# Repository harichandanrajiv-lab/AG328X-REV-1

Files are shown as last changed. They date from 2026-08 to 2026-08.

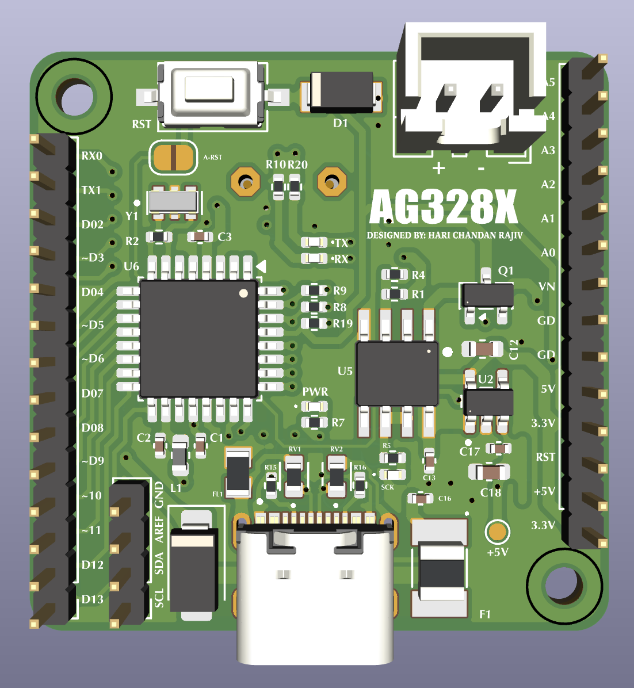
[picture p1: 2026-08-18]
Board Images/Top View.png

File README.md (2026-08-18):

# AG328X-REV-1
AG328X REV-1 is a compact, redesigned implementation of the Arduino UNO platform, developed with
the objective of improving the original UNO architecture in terms of form factor, power architecture, USB
connectivity, protection, serviceability, and PCB integration.

The design retains the core functionality based on the ATmega328P, while keeping a dedicated
ATmega16U2 USB-to-serial interface and a redesigned power-management architecture. Rather than
directly reproducing the conventional reference design, AG328X restructures several functional sections to
achieve a more compact and integrated hardware platform.

The complete PCB is designed with an overall dimension of 34 mm × 34 mm, a 1.6 mm finished board
thickness, and a 4-layer PCB stack-up, which is 68.44% smaller in size compared to the original UNO board.
The four-layer implementation provides additional routing resources and dedicated copper areas for power
and ground distribution, enabling the compact board dimensions without compromising the electrical
organization of the design. For further info, go through @Documentation Section.

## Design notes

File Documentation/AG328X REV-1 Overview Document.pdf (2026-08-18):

# AG328X REV-1 Description

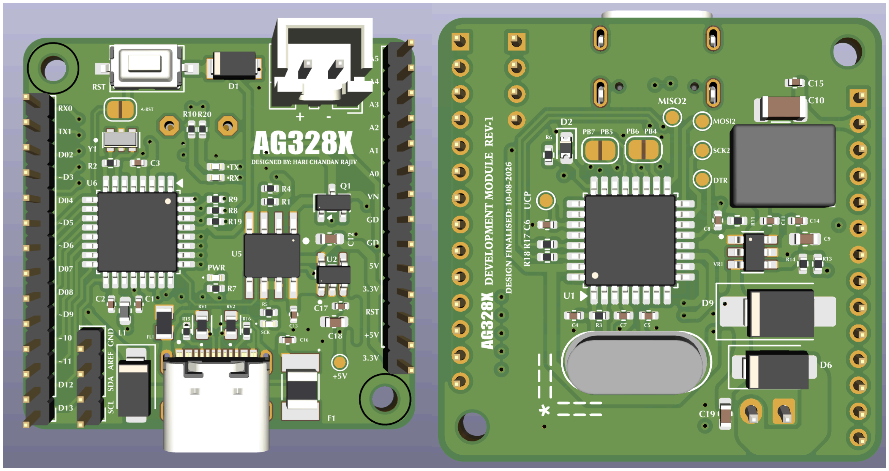
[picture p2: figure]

## 1.1 Introduction

AG328X REV-1 is a compact, redesigned implementation of the Arduino UNO platform, developed with the objective of improving the original UNO architecture in terms of form factor, power architecture, USB connectivity, protection, serviceability, and PCB integration.

The design retains the core functionality based on the ATmega328P, while keeping a dedicated
ATmega16U2 USB-to-serial interface and a redesigned power-management architecture. Rather than directly reproducing the conventional reference design, AG328X restructures several functional sections to achieve a more compact and integrated hardware platform.

The complete PCB is designed with an overall dimension of 34 mm × 34 mm, a 1.6 mm finished board thickness, and a 4-layer PCB stack-up, which is 68.44% smaller in size compared to the original UNO board. The four-layer implementation provides additional routing resources and dedicated copper areas for power and ground distribution, enabling the compact board dimensions without compromising the electrical organization of the design.

AG328X REV-1 ⬩ Designed by Hari Chandan Rajiv ⬩ 1

## 1.2 Design Objective

The primary objective of AG328X REV-1 is to develop a smaller and more technically refined UNO-compatible hardware platform while maintaining the essential functionality. The redesign focuses on the following engineering objectives:

- Reduction of the overall PCB footprint.
- Integration of the complete ATmega328P-based controller architecture onto a compact board.
- Replacement of the conventional USB-B connector arrangement with USB Type-C.
- Improvement of the input power and regulation architecture.
- Improvement on maximum input voltage VIN capability.
- Replacement of DC jack with a 2 pin JST connector for easy power connection.
- Controlled generation of the 3.3 V rail, including VIN/USBVCC source selection.
- Incorporation of input protection and power filtering.
- Improved PCB routing capability through a 4-layer architecture.
- Maintaining access to the standard Arduino I/O functionality through board connectors.

## 1.3 System Architecture

The AG328X REV-1 hardware is organized around two primary microcontrollers:

1. ATmega328P — Main application microcontroller responsible for the Arduino-compatible processing and I/O functionality.
2. ATmega16U2 — Dedicated USB interface controller responsible for USB-to-UART communication with the ATmega328P.

The schematic is divided into functional blocks covering the USB interface, power management, microcontroller circuitry, indication circuitry, and external I/O interfaces. The power architecture is independently organized around the incoming VIN and USB VCC sources. The design includes a dedicated 5 V regulator section for generating the primary regulated supply and a separate 3.3 V supply section with source-selection circuitry. Input protection, filtering, bulk capacitance, and local decoupling are incorporated around the power stages to improve supply integrity.

The USB section uses a USB Type-C connector together with the required CC configuration and USB signal routing. A ferrite-bead-based filtering arrangement is also incorporated into the USB-related power/ground path.

AG328X REV-1 ⬩ Designed by Hari Chandan Rajiv ⬩ 2

# 2. Technical Specifications

## 2.1 Electrical and System Specifications

Parameter | AG328X REV-1 Specification | Design Basis
Main Controller | ATmega328P-AU | 32 KB Flash, 2 KB SRAM, 1 KB EEPROM
USB Controller | ATmega16U2 | Dedicated USB-to-UART interface
Main Logic Voltage | 5 V | Regulated supply
Auxiliary Logic Voltage | 3.3 V | Dedicated LDO
VIN Input | 17 V maximum | Regulator Input capability
5 V Regulator Input Capability | 4.5–17 V | TPS561208-class buck regulator
3.3 V LDO Input | 5.5 V maximum | TLV70233
USB Interface | USB 2.0 | ATmega16U2

AG328X REV-1 ⬩ Designed by Hari Chandan Rajiv ⬩ 3

USB Connector | USB Type-C | For easy power and coding accessibility
PCB Dimensions | 34 mm × 34 mm | Mechanical design
Reverse Polarity Protection | FDN340P | PMOS transistor based reverse polarity and dual input protection
PCB Thickness | 1.6 mm | PCB specification
PCB Layer Count | 4 layers | Routing and ground/power architecture

The ATmega328P supports a 1.8–5.5 V supply range, while the ATmega16U2 supports 2.7–5.5 V. Both therefore operate within their specified supply ranges on the 5 V AG328X logic rail. (Microchip) (https://www.microchip.com/en-us/product/ATmega328p?utm_source=chatgpt.com)

## 2.2 VIN Capability and Input Protection

The VIN power path is one of the major improvements in AG328X REV-1. The input passes through a resettable PPTC fuse, reverse-polarity protection diode, and transient-voltage suppression device before reaching the regulator stage.

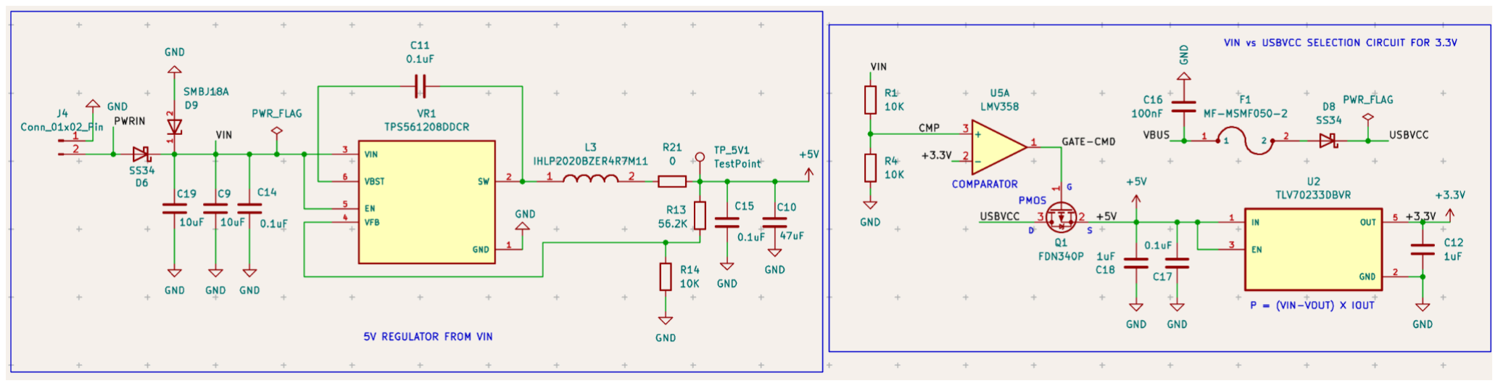
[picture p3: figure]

### VIN Rating Analysis

AG328X REV-1 ⬩ Designed by Hari Chandan Rajiv ⬩ 4

The selected 5 V switching regulator provides an input operating range extending to 17 V. For the TPS561201, for example, the specified input range is 4.5–17 V, with a 1 A output capability. (Texas Instruments) (https://www.ti.com/product/TPS561201?utm_source=chatgpt.com)

However, the overall AG328X VIN rating is determined by the lowest-rated component in the VIN path, not by the regulator alone.

The selected Bourns MF-MSMF050-2 has:

- Hold current: 500 mA
- Trip current: 1 A
- Maximum voltage: 15 VDC
- Maximum current: 100 A
- Maximum resistance: approximately 1 Ω (Mouser Electronics) (https://www.mouser.com/en/ProductDetail/Bourns/MF-MSMF050-2?qs=t3shhpq1i1DZ7OBD5kLNoA%3D%3D)

Therefore: The present AG328X REV-1 VIN capability should be 15 V maximum, not 17 V.

The 17 V capability of the buck regulator provides voltage headroom within the regulator itself, but the 15 V PPTC rating limits the complete input path.

### Input Protection Devices

The VIN protection network includes the following devices:

Component | Selected Part | Rating / Function
F1 | MF-MSMF050-2 | 500 mA hold, 1 A trip, 15 V maximum
D6 | SS34 | Schottky reverse-polarity protection
D9 | SMBJ18A | 18 V TVS protection
C19/C9/C14 | Input capacitors | VIN filtering and transient energy storage

AG328X REV-1 ⬩ Designed by Hari Chandan Rajiv ⬩ 5

The SMBJ18A provides an 18 V working standoff voltage, 20 V minimum breakdown voltage and approximately 29.2 V maximum clamping voltage, with a 600 W peak pulse capability for the specified pulse condition. (Diodes Incorporated) (https://www.diodes.com/part/view/SMBJ18A?utm_source=chatgpt.com)

This provides appropriate transient protection around the intended VIN region, but it does not change the continuous operating-voltage limit imposed by the PPTC fuse.

## 2.3 5 V Power Supply

AG328X REV-1 uses a dedicated synchronous buck regulator to generate the primary 5 V rail from VIN.

The selected regulator is a TPS56x-series 17 V-input synchronous step-down converter. The relevant device family provides:

- Input voltage: 4.5–17 V
- Output voltage range: approximately 0.76–7 V
- Synchronous rectification
- Integrated switching MOSFETs
- Cycle-by-cycle overcurrent protection
- Hiccup-mode overcurrent protection
- Thermal shutdown
- Undervoltage protection
- Approximately 580 kHz switching frequency for the TPS56120x family. (Texas Instruments) (https://www.ti.com/product/TPS561201?utm_source=chatgpt.com)

The regulator is configured for a fixed 5 V output, which becomes the primary supply rail for the ATmega328P, ATmega16U2 and associated 5 V circuitry.

### System Implication

The regulator selection provides considerably more input-voltage capability than the conventional 5 V logic rail requires:

VIN → Protection → 5 V Buck Converter → +5 V Logic Rail

The important distinction is:

- Regulator capability: up to 17 V
- Present AG328X system VIN rating: 15 V
- Reason: MF-MSMF050-2 maximum voltage rating

AG328X REV-1 ⬩ Designed by Hari Chandan Rajiv ⬩ 6

This distinction is maintained throughout this document to prevent confusing individual component ratings with the system rating.

## 2.4 3.3 V Power Supply

The 3.3 V rail is generated using the TLV70233 low-dropout regulator.

The TLV70233 is a fixed 3.3 V LDO with:

- Output voltage: 3.3 V
- Output current capability: 300 mA
- Maximum input voltage: 5.5 V
- Low quiescent current
- Low-noise operation
- Thermal and current protection. (Texas Instruments) (https://www.ti.com/lit/ds/symlink/tlv700-q1.pdf?ts=1778681428301&utm_source=chatgpt.com)

In AG328X, the regulator is supplied from the 5 V domain, rather than directly from VIN.

Therefore, the 3.3 V regulator does not impose a 5.5 V limit on the AG328X VIN input.

The power architecture can consequently be represented as:

VIN → 5 V Buck → 5 V Rail → 3.3 V LDO → 3.3 V Rail

This allows the board to accept the higher VIN voltage permitted by the upstream power architecture while keeping the 3.3 V regulator safely within its input specification.

## 2.5 3.3 V Supply-Source Selection

AG328X REV-1 incorporates an active supply-selection circuit around an LMV358 comparator and FDN340P P-channel MOSFET to control the 3.3 V supply source.

The LMV358 operates from 2.7–5.5 V and provides rail-to-rail output capability, making it suitable for the 5 V-powered comparison/control section used in the design. (Texas Instruments) (https://www.ti.com/product/LMV358?utm_source=chatgpt.com)

The selected FDN340P is a logic-level P-channel MOSFET with:

AG328X REV-1 ⬩ Designed by Hari Chandan Rajiv ⬩ 7

- Drain-source voltage: 20 V
- Continuous drain current: approximately 2 A
- RDS(on): approximately 70 mΩ at VGS = −4.5 V
- Maximum gate-source voltage: ±8 V
- Power dissipation: approximately 500 mW
- SOT-23 package. (DigiKey) (https://www.digikey.com/en/htmldatasheets/production/64543/0/0/1/fdn340p.html?utm_source=chatgpt.com)

This provides adequate voltage margin for the 5 V-domain source-selection function.

## 2.6 5 V Regulator Architecture and Power-Loss Improvement

A significant change in AG328X REV-1 is the replacement of the conventional 5 V linear/LDO regulation approach with a switching buck regulator.

This change was made primarily to reduce power dissipation and improve power-conversion efficiency, particularly when AG328X is operated from a higher VIN voltage.

### Linear Regulator vs. Switching Regulator

With a conventional linear regulator, the excess input voltage is dissipated directly as heat. The regulator power loss is approximately:

PLOSS(LDO) = (VIN − VOUT) × IOUT

For the AG328X 5 V rail:

PLOSS(LDO) = (VIN − 5 V) × IOUT

As VIN increases, the voltage dropped across the regulator increases, causing a corresponding increase in heat generation.

In contrast, the switching buck regulator used in AG328X transfers energy from the input to the output through high-frequency switching. Its power loss is primarily determined by the converter’s efficiency:

PLOSS(BUCK) = POUT × (1/η − 1)

where:

- POUT = output power
- η = converter efficiency

AG328X REV-1 ⬩ Designed by Hari Chandan Rajiv ⬩ 8

Therefore, the switching architecture avoids dissipating the entire VIN-to-5 V voltage difference as heat.

### Example Power-Loss Comparison

Consider a representative operating condition of:

- VIN = 15 V
- VOUT = 5 V
- IOUT = 500 mA

The 5 V output power is:

POUT = 5 V × 0.5 A = 2.5 W

a. Conventional LDO

For a linear regulator: PLOSS = (15 − 5) × 0.5 = 5 W

The regulator would therefore need to dissipate approximately 5 W as heat while delivering only 2.5 W to the 5 V load. The theoretical efficiency would be:

ηLDO = 5/15 ≈ 33.3%

This creates a significant thermal-management requirement and makes operation from higher VIN voltages inefficient.

b. Switching Buck Regulator

Assuming a representative converter efficiency of 90%:

PIN = 2.5 W / 0.90 ≈ 2.78 W

Therefore: PLOSS ≈ 2.78 − 2.5 = 0.28 W

Parameter | 5 V LDO | 5 V Switching Regulator

AG328X REV-1 ⬩ Designed by Hari Chandan Rajiv ⬩ 9

VIN | 15 V | 15 V
VOUT | 5 V | 5 V
Load Current | 500 mA | 500 mA
Output Power | 2.5 W | 2.5 W
Approx. Efficiency | 33.3% | ~90%*
Approx. Regulator Loss | 5.0 W | 0.28 W*
Heat Generation | High | Significantly lower

Actual switching-regulator efficiency depends on VIN, load current, switching frequency, inductor, PCB layout, temperature, and other operating conditions. The 90% value is an illustrative engineering example and should not be treated as the guaranteed AG328X efficiency.

### Effect on AG328X

The change to a switching 5 V regulator provides several practical advantages:

### 1. Lower power dissipation

The voltage difference between VIN and 5 V is no longer converted predominantly into heat.

### 2. Improved efficiency at higher VIN

The advantage becomes increasingly significant as VIN increases.

### 3. Reduced thermal stress

Lower regulator dissipation reduces junction-temperature rise and thermal stress on the PCB.

AG328X REV-1 ⬩ Designed by Hari Chandan Rajiv ⬩ 10

### 4. Improved usable VIN range

The selected switching regulator supports input voltages up to 17 V, while the present AG328X system-level VIN rating is limited to 15 V by the MF-MSMF050-2 input protection fuse.

### 5. Better suitability for continuous operation

Lower dissipation is particularly advantageous when the board operates continuously or is enclosed with limited airflow.

### 6. Higher practical power capability

Because less input power is lost as heat, a larger portion of the available input power can be delivered to the 5 V rail.

### Engineering Significance

The regulator change is therefore not simply a component substitution. It represents a power-architecture improvement in AG328X REV-1.

Design conclusion: The adoption of a switching regulator for the 5 V rail significantly reduces the power that would otherwise be dissipated as heat by a linear regulator, making the AG328X power architecture more efficient and thermally suitable for operation from higher VIN voltages.

## 2.7 Current Consumption and Power-Architecture Comparison

A further objective of AG328X REV-1 is to reduce unnecessary power consumption and, more importantly, reduce the power lost within the board’s voltage-regulation circuitry.

### Arduino UNO R3 Reference

The Arduino UNO R3 is specified for a 5 V operating voltage and uses a linear regulation approach when powered through VIN. Arduino’s current power-supply guidance indicates that a basic Arduino board typically requires approximately 50 mA, excluding external loads connected to the board. (Arduino Help Center) (https://support.arduino.cc/hc/en-us/articles/360018922259-What-power-supply-can-I-use-with-my-Arduino-board)

The actual input power when using VIN depends strongly on the applied voltage because a linear regulator dissipates the voltage difference as heat.

For example, at:

- VIN = 12 V
- 5 V rail current = 50 mA

AG328X REV-1 ⬩ Designed by Hari Chandan Rajiv ⬩ 11 the approximate regulator dissipation is: PLOSS = (12 − 5) × 0.05 = 0.35 W

The input power associated with the 50 mA load is approximately: PIN = 12 × 0.05 = 0.60 W

while the useful 5 V power is: POUT = 5 × 0.05 = 0.25 W

This illustrates why the UNO’s linear-regulator architecture becomes increasingly inefficient as VIN increases.

### AG328X REV-1

AG328X replaces the conventional 5 V linear-regulation approach with a switching buck regulator. Consequently, the input current is no longer approximately equal to the 5 V load current when operating from VIN.

For a buck converter:

IIN ≈ (VOUT × IOUT) / (VIN × η)

where η is the converter efficiency.

For example, assuming:

- VIN = 12 V
- 5 V load current = 50 mA
- Converter efficiency = 90%

the approximate VIN current becomes:

IIN ≈ (5 × 0.05) / (12 × 0.90) ≈ 23 mA

The corresponding input power is approximately:

PIN ≈ 12 × 23 mA ≈ 0.28 W

Therefore, compared with a linear regulator, the switching architecture substantially reduces the power drawn from VIN for the same 5 V load and dramatically reduces regulator heat dissipation.

### Preliminary Comparison

AG328X REV-1 ⬩ Designed by Hari Chandan Rajiv ⬩ 12

Parameter | Arduino UNO R3 | AG328X REV-1

The AG328X value is an engineering calculation based on an assumed 50 mA 5 V load and 90% converter efficiency. It is not a measured AG328X specification.

AG328X REV-1 ⬩ Designed by Hari Chandan Rajiv ⬩ 13

Main MCU | ATmega328P | ATmega328P
USB MCU | ATmega16U2 | ATmega16U2
Logic Voltage | 5 V | 5 V
5 V Regulation | Linear | Switching Buck
Typical board current* | ~50 mA | To be measured
VIN example | 12 V | 12 V
5 V load used for example | 50 mA | 50 mA
Approx. VIN current at 12 V | ~50 mA | ~23 mA*
Approx. regulator loss | ~350 mW | ~28 mW*
Regulation efficiency | ~42% theoretical | ~90% assumed*

### Engineering Conclusion

The principal improvement is therefore not necessarily that AG328X consumes fewer milliamps at every operating condition. The more significant improvement is that AG328X requires less input power and generates substantially less heat when converting higher VIN voltages to the 5 V logic rail.

For the same 5 V load:

Arduino UNO linear regulation:

Higher VIN → approximately same input current → higher power loss

AG328X switching regulation:

Higher VIN → lower input current → substantially lower power loss

This makes the AG328X architecture more suitable for compact applications where thermal dissipation, continuous operation, and power efficiency are important design considerations.

AG328X REV-1 ⬩ Designed by Hari Chandan Rajiv ⬩ 14

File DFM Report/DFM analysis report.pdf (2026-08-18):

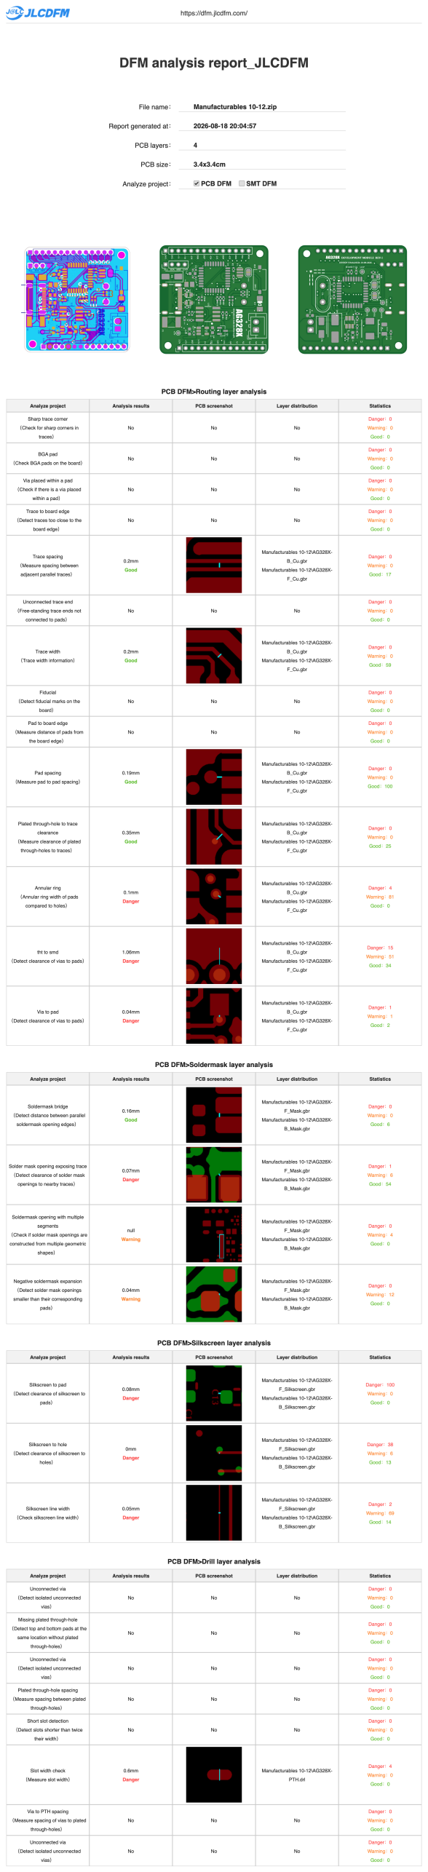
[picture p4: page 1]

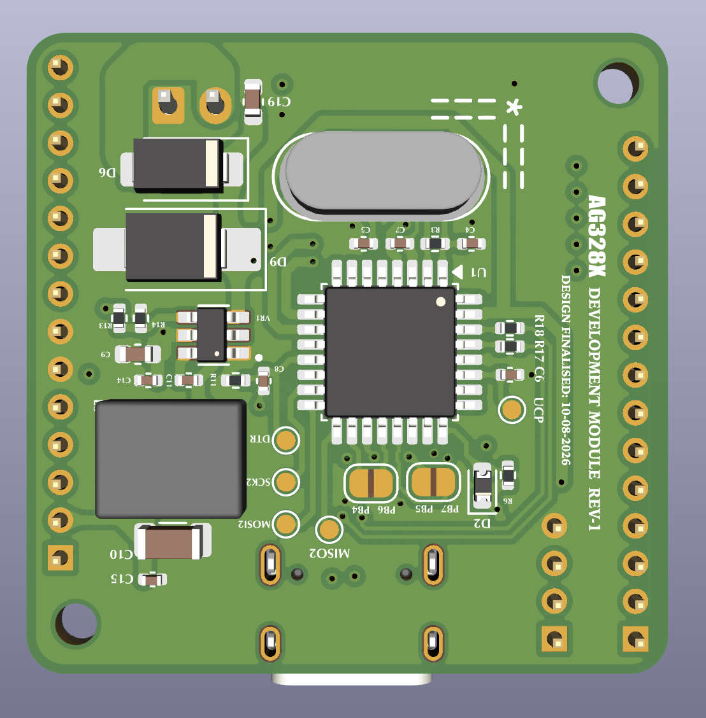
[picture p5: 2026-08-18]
Board Images/Bottom View.png

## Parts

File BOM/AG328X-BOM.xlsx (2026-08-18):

AG328X
Id | Designator | Footprint | Designation | Quantity | Cost | Total | Source Link
1 | C1, C2, C3, C7, C8, C13, C16 | C_0402_1005Metric | 100nF | 7 | 0.5 | 3.5 | https://robu.in/product/gcm155r71h104ke02j-murata-electronics-50v-100nf-x7r-%C2%B110-0402-multilayer-ceramic-capacitors-mlcc-smd-smt-rohs/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
2 | C4, C5 | C_0402_1005Metric | 22pF | 2 | 0.23 | 0.46 | https://robu.in/product/grm1555c1h220ga01d-murata-cap-ceramic-22pf-50v-c0g-2-pad-smd-0402-125c-t-r/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
3 | C6 | C_0402_1005Metric | 1uF | 1 | 0.31 | 0.31 | https://robu.in/product/grm155b31c105ka12d-murata-cap-ceramic-1uf-16v-b-10-pad-smd-0402-85c-t-r/?gad_source=1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
4 | C9, C19 | C_0603_1608Metric | 10uF | 2 | 2.34 | 4.68 | https://robu.in/product/grm188r61e106ma73d-murata-cap-ceramic-10uf-25v-x5r-20-pad-smd-0603-85c-automotive-t-r/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
5 | C10 | C_1206_3216Metric | 47uF | 1 | 33 | 33 | https://robu.in/product/grm31cr61e476me44l-murata-25v-47uf-x5r-%25c2%25b120-1206-multilayer-ceramic-capacitors-mlcc-smd-smt-rohs/
6 | C11, C14, C15, C17 | C_0402_1005Metric | 0.1uF | 4 | 0.5 | 2 | https://robu.in/product/gcm155r71h104ke02j-murata-electronics-50v-100nf-x7r-%C2%B110-0402-multilayer-ceramic-capacitors-mlcc-smd-smt-rohs/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
7 | C12, C18 | C_0603_1608Metric | 1uF | 2 | 0.5 | 1 | https://robu.in/product/grm188r71e105ka12d-murata-cap-ceramic-1uf-25v-x7r-10-pad-smd-0603-125c-t-r/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
8 | D1 | SS14 | DO-214AC | 1 | 1.35 | 1.35 | https://robu.in/product/ss14-slkor-40v-550mv1a-1a-smado-214ac-schottky-diodes-rohs/?gad_source=1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
9 | D2 | D_0603_1608Metric | SDM2U30CSP-7B | 1 | 16 | 16 | https://robu.in/product/sdm2u30csp-7b-diodes-incorporated-30v-480mv2a-2a-0603-schottky-diodes-rohs/
10 | D3 | LED_0402_1005Metric | LED - WHITE | 1 | 1.69 | 1.69 | https://robu.in/product/0402-surface-mount-led-white/
11 | D4 | LED_0402_1005Metric | LED-ORANGE | 1 | 1.79 | 1.79 | https://robu.in/product/0402-surface-mount-led-orange/
12 | D5 | LED_0402_1005Metric | LED - GREEN | 1 | 1.91 | 1.91 | https://robu.in/product/0402-surface-mount-led-green-50-pcs/
13 | D6, D8 | D_SMA | SS34 | 2 | 2.47 | 4.94 | https://robu.in/product/ss34-slkor-40v-500mv3a-3a-smado-214ac-schottky-diodes-rohs/?gad_source=1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
14 | D7 | LED_0402_1005Metric | LED-YELLOW | 1 | 1.77 | 1.77 | https://robu.in/product/0402-surface-mount-led-yellow/
15 | D9 | D_SMB_Handsoldering | SMBJ18A | 1 | 20 | 20 | https://robu.in/product/smbj18a-13-f-diodes-incorporated-20-5a-600w-29-2v-23-3v-unidirectional-18v-smbdo-214aa-esd-and-surge-protection-tvs-esd-rohs/
16 | F1 | FUSM4632X85 | MF-MSMF050-2 | 1 | 40.77 | 40.77 | https://www.lioncircuits.com/parts/MF-MSMF050-2
17 | FL1 | BEADC2012X105N | BLM21PG121SN1D | 1 | 15.93 | 15.93 | https://www.lioncircuits.com/parts/BLM21PG121SN1D
18 | J1 | PinHeader_1x04_P2.00mm_Vertical | Conn_01x04_Socket | 1 | 0 | 0 | https://robu.in/product/2mm-pitch-male-berg-strip-40x1-2pcs/
19 | J2 | GCT_USB4105GFA | USB4105GFA | 1 | 5.5 | 5.5 | https://www.ktron.in/product/16-pin-usb-type-c-connector-smd/
20 | J4 | JST_XA_B02B-XASK-1-A_1x02_P2.50mm_Vertical | Conn_01x02_Pin | 1 | 8 | 8 | https://robu.in/product/2-pin-jst-xh-2-54mm-pitch-plug-and-socket-with-cable-10-pcs/
21 | J11, J12 | PinHeader_1x14_P2.00mm_Vertical | Conn_01x14_Socket | 2 | 12.5 | 25 | https://robu.in/product/2mm-pitch-male-berg-strip-40x1-2pcs/
22 | L1 | L_0603_1608Metric | 10uH | 1 | 3.73 | 3.73 | https://robu.in/product/mlz1608m100wt000-tdk-10-%C2%B5h-shielded-multilayer-inductor-250-ma-1-05ohm-0603-1608-metric/
23 | L3 | INDPM5552X200N | IHLP2020BZER4R7M11 | 1 | 12 | 12 | https://robu.in/product/ihlp2020bzer4r7m11-vishay-power-inductor-smd-4-7-%25c2%25b5h-3-2-a-shielded-3-a/
24 | Q1 | SOT-23 | FDN340P | 1 | 6 | 6 | https://robu.in/product/fdn340p-slkor-20v-3a-1w-70m%CF%894-5v2a-1v-1-piece-p-channel-sot-23-mosfets-rohs/
25 | R1, R4, R6, R14, R19 | R_0402_1005Metric | 10K | 5 | 0.36 | 1.8 | https://robu.in/product/rc0402fr-1010kl-yageo-0-063w-thick-film-resistors-%25c2%25b1100ppm-%25e2%2584%2583-%25c2%25b11-10k%25cf%2589-0402-chip-resistor-surfac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
26 | R2, R3 | R_0402_1005Metric | 1M ohm | 2 | 0.67 | 1.34 | https://robu.in/product/rc0402fr-071ml-yageo-res-thick-film-0402-1m-ohm-1-0-063w1-16w-%C2%B1100ppm-c-pad-smd-t-r/
27 | R5, R8, R9, R10, R11, R20 | R_0402_1005Metric | 1K | 6 | 0.68 | 4.08 | https://robu.in/product/ac0402jr-071kl-yageo-res-thick-film-0402-1k-ohm-5-0-063w1-16w-%C2%B1100ppm-c-pad-smd-t-r-automotive-aec-q200/
28 | R7 | R_0402_1005Metric | 500 | 1 | 0 | 0 | Use 1k
29 | R13 | R_0402_1005Metric | 56.2K | 1 | 0.12 | 0.12 | https://robu.in/product/ac0402fr-0756k2l-yageo-res-thick-film-0402-56-2k-ohm-1-0-063w1-16w-%C2%B1100ppm-c-pad-smd-t-r-automotive-aec-q200/
30 | R15, R16 | R_0402_1005Metric | 5.1K | 2 | 0.13 | 0.26 | https://robu.in/product/rc0402fr-075k1l-yageo-smd-chip-resistor/
31 | R17, R18 | R_0402_1005Metric | 22 ohm | 2 | 0.69 | 1.38 | https://robu.in/product/rc0402fr-0722rl-yageo-smd-chip-resistor-22-ohm-%25c2%25b1-1-100-mw-0402-1005-metric-thick-film-precision-pack-of-10/
32 | RV1, RV2 | VARC1608X56N | CG0603MLC-05E | 2 | 27 | 54 | https://robu.in/product/cg0603mlc-05e-bourns-tvs-varistor-8-v-5-v-chipguard-mlc-20-v-0603-1608-metric-multilayer-varistor-mlv/
33 | SW1 | SW_Tactile_SPST_NO_Straight_CK_PTS636Sx25SMTRLFS | SW_Push | 1 | 2.71 | 2.71 | https://robu.in/product/lck-ta007h27-2wl-lckelec-362-7-patch-260g-tact-switch/
35 | U1 | TQFP-32_7x7mm_P0.8mm | ATmega16U2-A | 1 | 364.679 | 364.679 | https://in.element14.com/microchip/atmega16u2-au/mcu-8bit-16mhz-tqfp-32/dp/1841607
36 | U2 | SOT95P280X145-5N | TLV70233DBVR | 1 | 15.05 | 15.05 | https://www.ktron.in/product/tlv70233dbvr-regulator-ic/
37 | U5 | SO08 | LMV358 | 1 | 11 | 11 | https://robu.in/product/lmv358-slkor-dual-0-3v-us-1mhz-9mv-sop-8-operational-amplifier-rohs/
38 | U6 | TQFP-32_7x7mm_P0.8mm | ATmega328P-A | 1 | 326 | 326 | https://robu.in/product/atmega328p-au-microchip-8-bit-mcu-avr-atmega/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
39 | VR1 | SOT95P280X110-6N | TPS561208DDCR | 1 | 54 | 54 | https://robu.in/product/tps561208ddcr-texas-instruments-step-down-type-adjustable-760mv7v-1a-4-5v17v-tsot-23-6-dc-dc-converters-rohs/
40 | Y1 | OSC_CSTCE16M0V53-R0 | 16MHz Crystal | 1 | 37.52 | 37.52 | https://www.lioncircuits.com/parts/CSTNE16M0VH3C000R0
41 | Y2 | 16MHz Y2 | 16MHz Crystal | 1 | 8 | 8 | https://robu.in/product/hc49-s-16mhz-crystal-oscillator-pack-of-5/
 |  |  |  |  |  | 1093.269

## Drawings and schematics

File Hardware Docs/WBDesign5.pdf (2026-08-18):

## WEBENCH ® Design Report

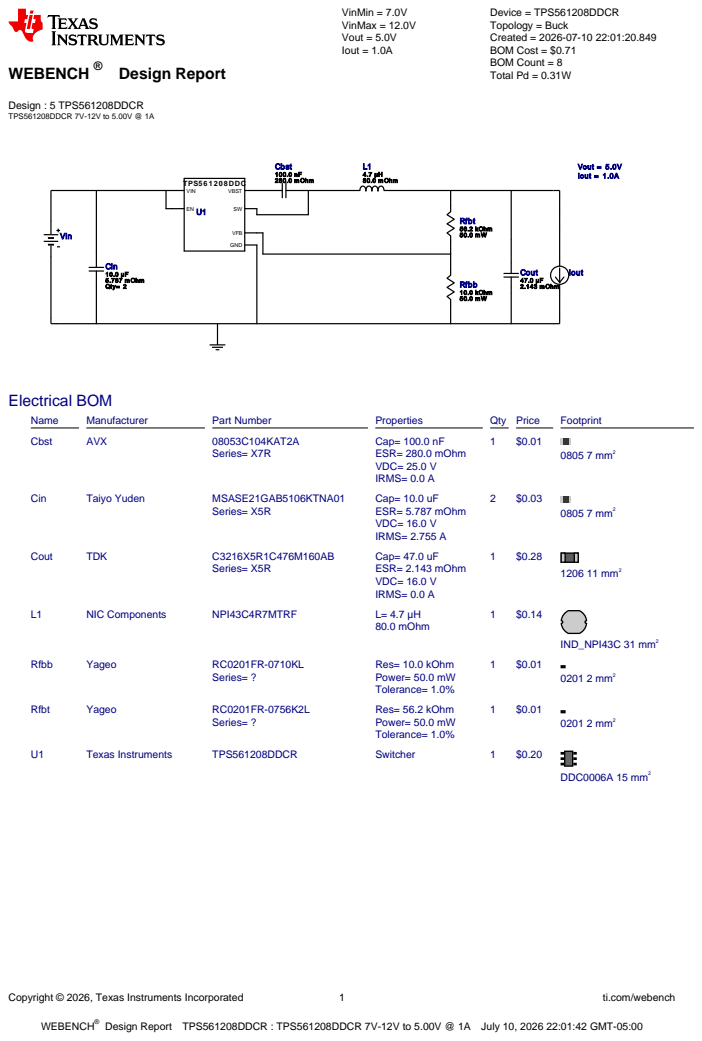
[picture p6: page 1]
Copyright © 2026, Texas Instruments Incorporated; ti.com/webench; WEBENCH®; Design : 5 TPS561208DDCR TPS561208DDCR 7V-12V to 5.00V @ 1A; VinMin = 7.0V VinMax = 12.0V Vout = 5.0V Iout = 1.0A; Device = TPS561208DDCR Topology = Buck Created = 2026-07-10 22:01:20.849 BOM Cost = $0.71 BOM Count = 8 Total Pd = 0.31W; Cbst 100.0 nF 280.0 m Ohm; Cin 10.0 µF 5.787 m Ohm Qty= 2; Cout 47.0 µF 2.143 m Ohm; L1 4.7 µH 80.0 m Ohm; Rfbb 10.0 kOhm 50.0 m W; TPS5 6 1 2 0 8 DDC; GND; VIN; VFB; VBST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

Design Report TPS561208DDCR : TPS561208DDCR 7V-12V to 5.00V @ 1A July 10, 2026 22:01:42 GMT-05:00

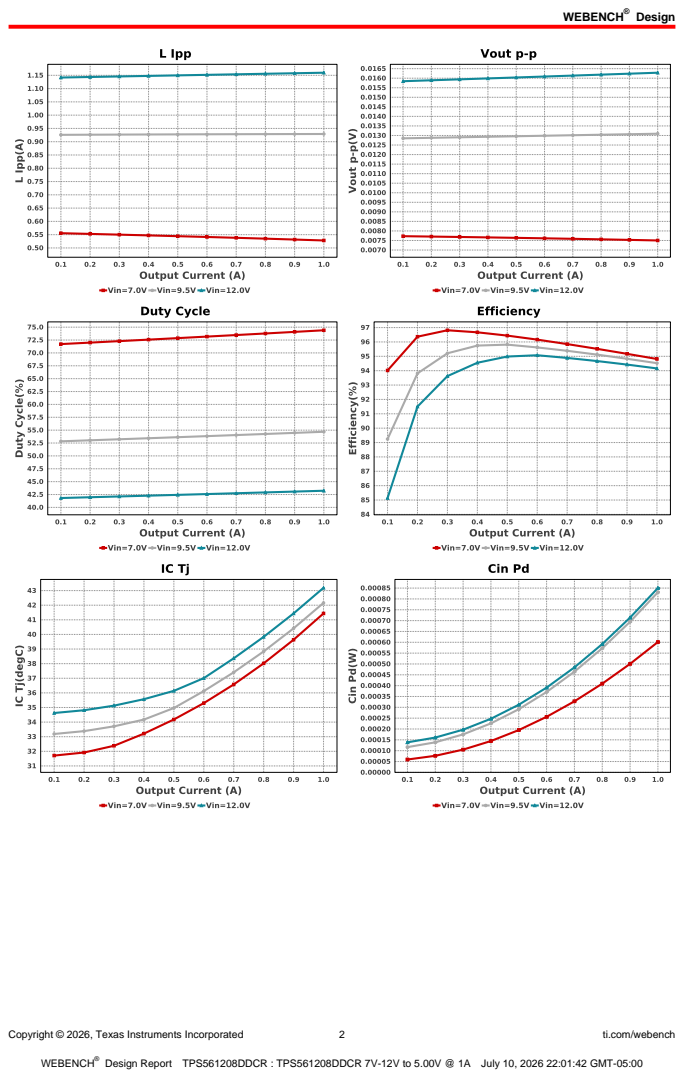
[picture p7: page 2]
Design; Copyright © 2026, Texas Instruments Incorporated; ti.com/webench

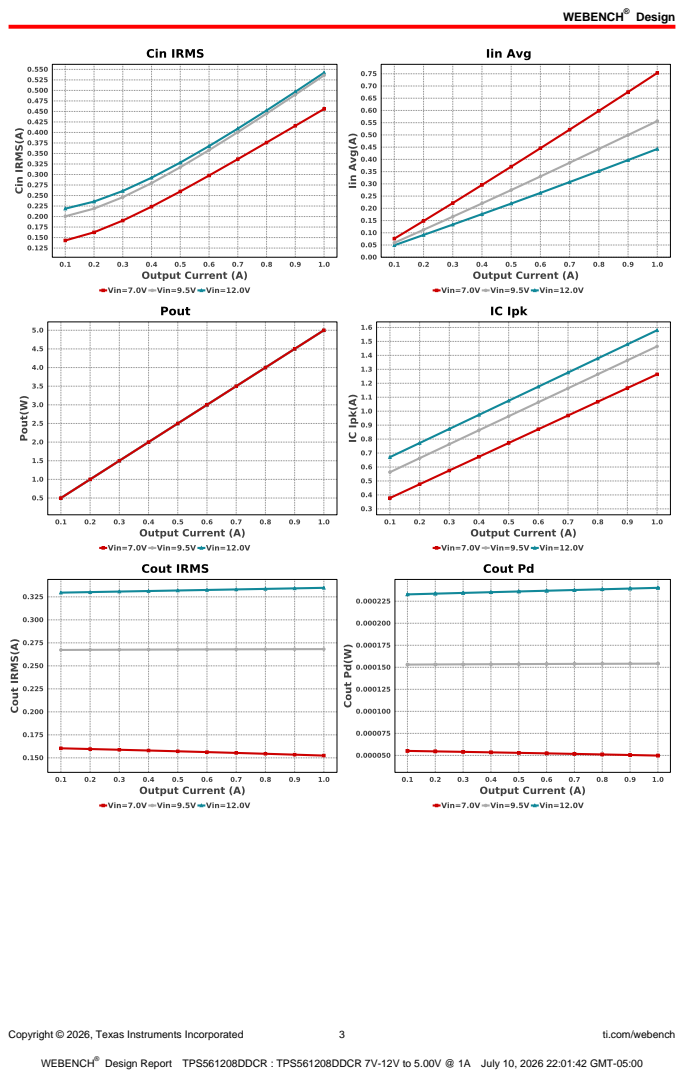
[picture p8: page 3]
Copyright © 2026, Texas Instruments Incorporated; ti.com/webench

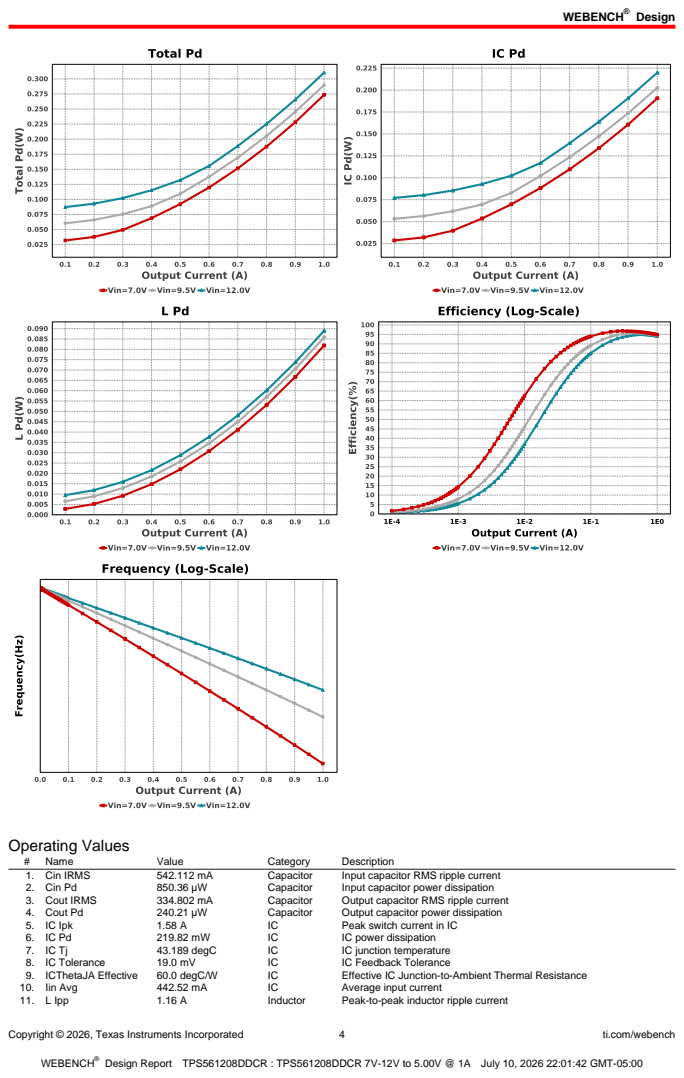
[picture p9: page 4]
Copyright © 2026, Texas Instruments Incorporated; ti.com/webench; Operating Values; Name; Value; Category; Description; 1. Cin IRMS; Capacitor; Input capacitor RMS ripple current; 2. Cin Pd; Input capacitor power dissipation; 3. Cout IRMS; Output capacitor RMS ripple current; 4. Cout Pd; Output capacitor power dissipation; 5. IC Ipk; Peak switch current in IC; IC power dissipation; 43.189 degC; IC junction temperature; 8. IC Tolerance; IC Feedback Tolerance; 9. ICThetaJA Effective; 60.0 degC/W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

Copyright © 2026, Texas Instruments Incorporated | 5 | ti.com/webench
# | Name | Value | Category | Description

12. L Pd | 88.967 mW | Inductor | Inductor power dissipation
13. Cin Pd | 850.36 µW | Power | Input capacitor power dissipation
14. Cout Pd | 240.21 µW | Power | Output capacitor power dissipation
15. IC Pd | 219.82 mW | Power | IC power dissipation
16. L Pd | 88.967 mW | Power | Inductor power dissipation
17. Total Pd | 310.277 mW | Power | Total Power Dissipation
18. BOM Count | 8 | System
| | | Information | Total Design BOM count
19. Duty Cycle | 43.235 % | System
| | | Information | Duty cycle
20. Efficiency | 94.157 % | System
| | | Information | Steady state efficiency
21. FootPrint | 81.0 mm² | System
| | | Information | Total Foot Print Area of BOM components
22. Frequency | 537.285 kHz | System
| | | Information | Switching frequency
23. Iout | 1.0 A | System
| | | Information | Iout operating point
24. Mode | CCM | System
| | | Information | Conduction Mode
25. Pout | 5.0 W | System
| | | Information | Total output power
26. Total BOM | $0.71 | System
| | | Information | Total BOM Cost
27. Vin | 12.0 V | System
| | | Information | Vin operating point
28. Vout | 5.0 V | System
| | | Information | Operational Output Voltage
29. Vout Actual | 5.084 V | System
| | | Information | Vout Actual calculated based on selected voltage divider resistors
30. Vout Tolerance | 4.231 % | System
| | | Information | Vout Tolerance based on IC Tolerance (no load) and voltage divider resistors if applicable
31. Vout p-p | 16.287 mV | System
| | | Information | Peak-to-peak output ripple voltage

## Design Inputs

Name | Value | Description
Iout | 1.0 | Maximum Output Current
VinMax | 12.0 | Maximum input voltage
VinMin | 7.0 | Minimum input voltage
Vout | 5.0 | Output Voltage
| base_pn | | TPS561208 | Base Product Number
source | DC | Input Source Type
Ta | 30.0 | Ambient temperature


Copyright © 2026, Texas Instruments Incorporated | 6 | ti.com/webench

## Assembly

## Component Testing

Some published data on components in datasheets such as Capacitor ESR and Inductor DC resistance is based on conservative values that will guarantee that the components always exceed the specification. For design purposes it is usually better to work with typical values. Since this data is not always available it is a good practice to measure the Capacitance and ESR values of Cin and Cout, and the inductance and DC resistance of L1 before assembly of the board. Any large discrepancies in values should be electrically simulated in WEBENCH to check for instabilities and thermally simulated in WebTHERM to make sure critical temperatures are not exceeded.
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

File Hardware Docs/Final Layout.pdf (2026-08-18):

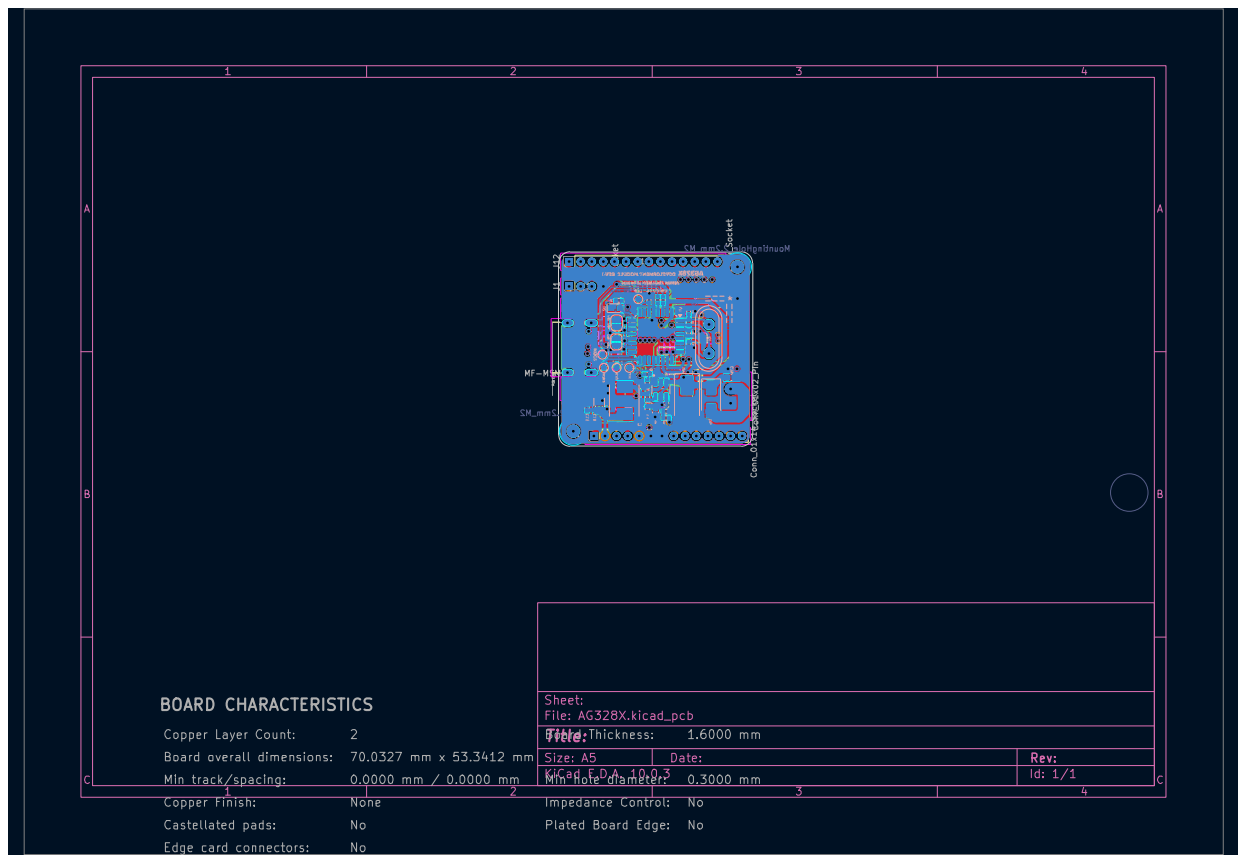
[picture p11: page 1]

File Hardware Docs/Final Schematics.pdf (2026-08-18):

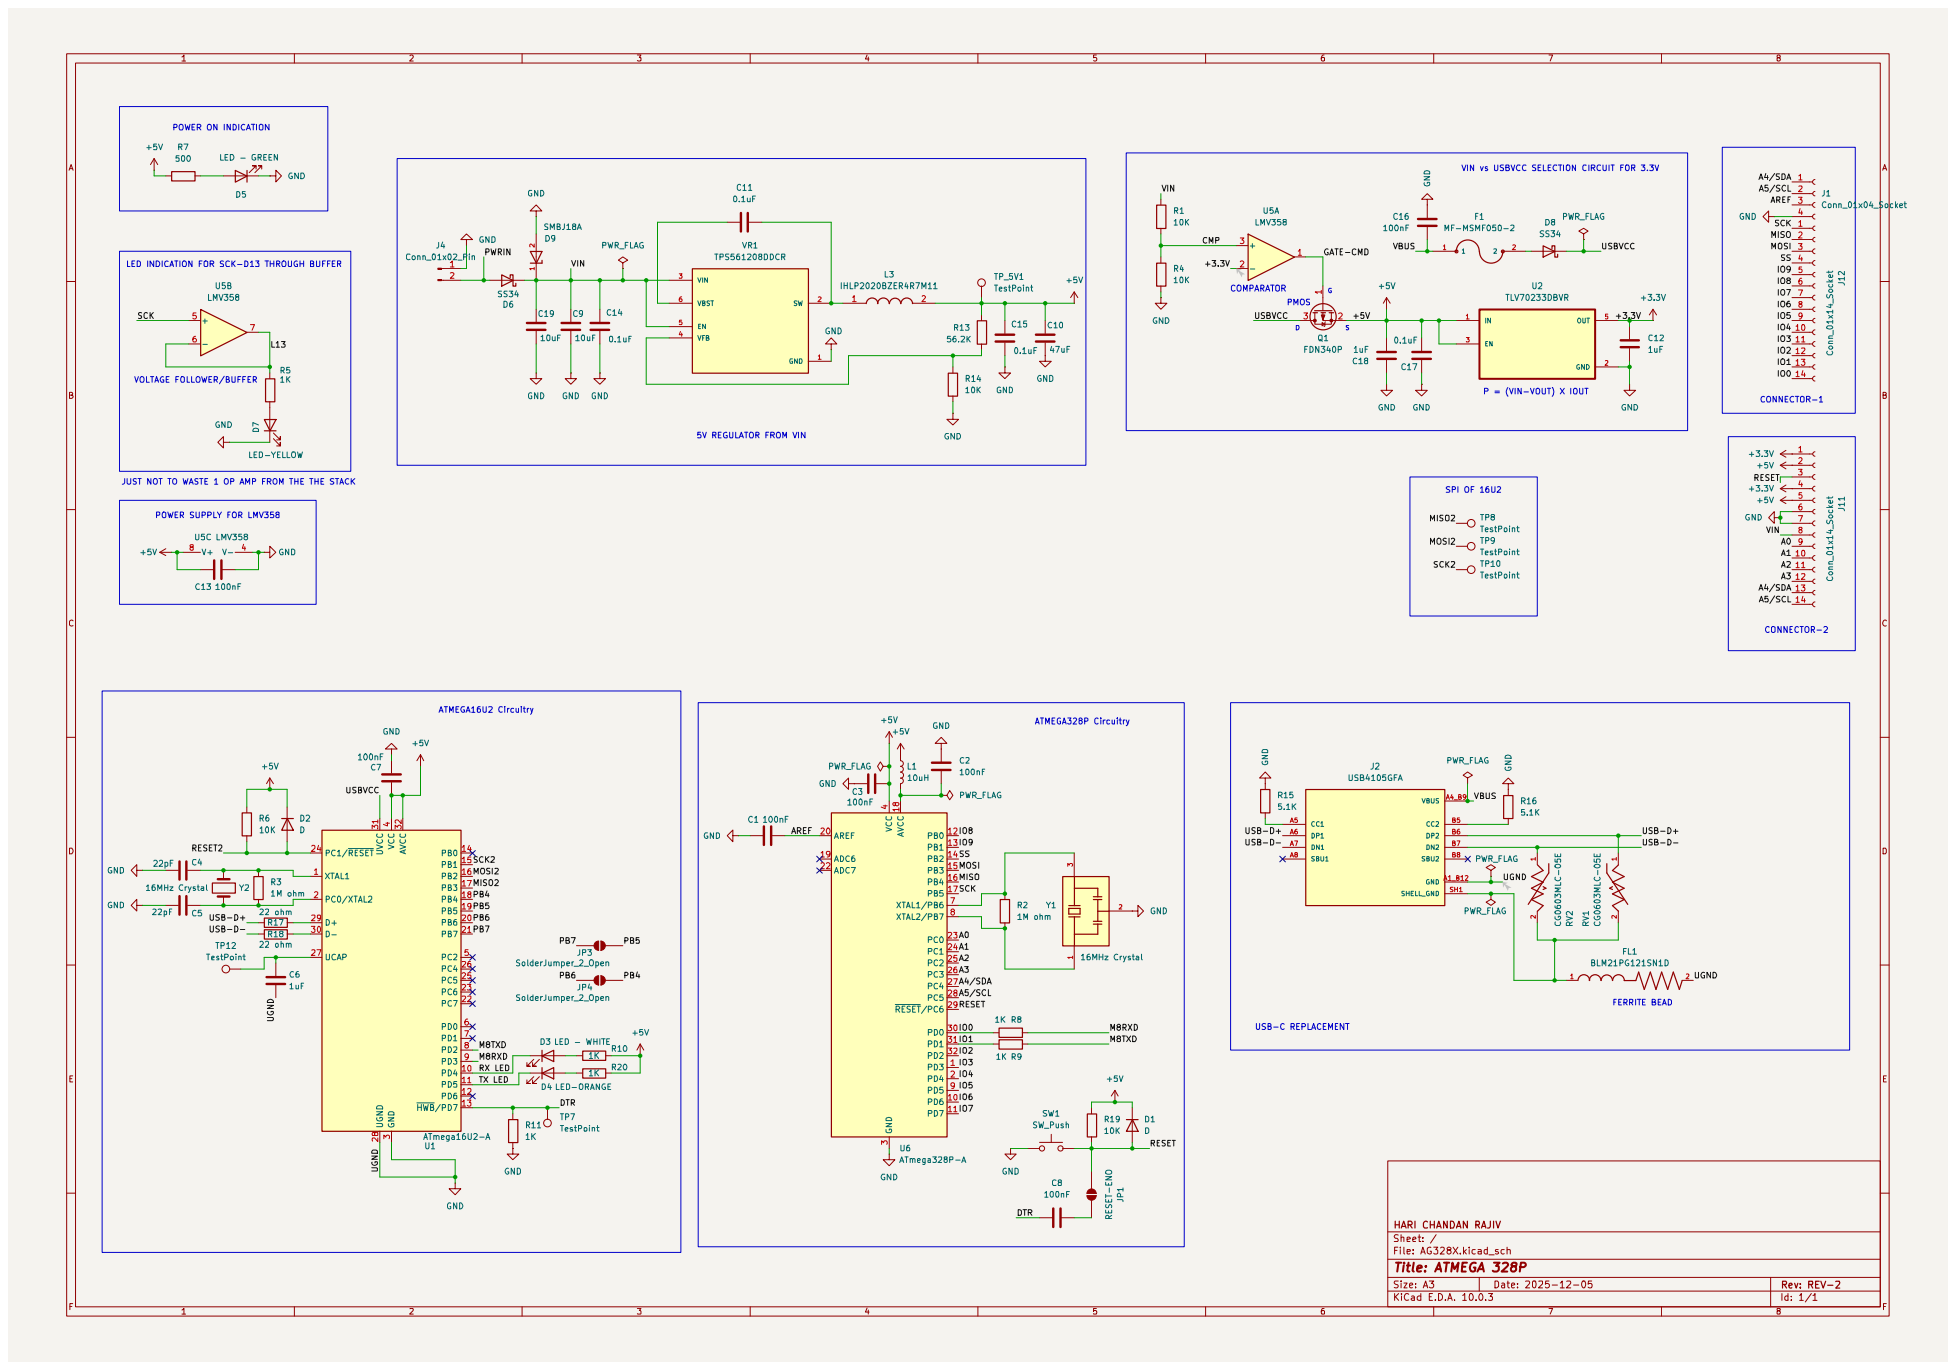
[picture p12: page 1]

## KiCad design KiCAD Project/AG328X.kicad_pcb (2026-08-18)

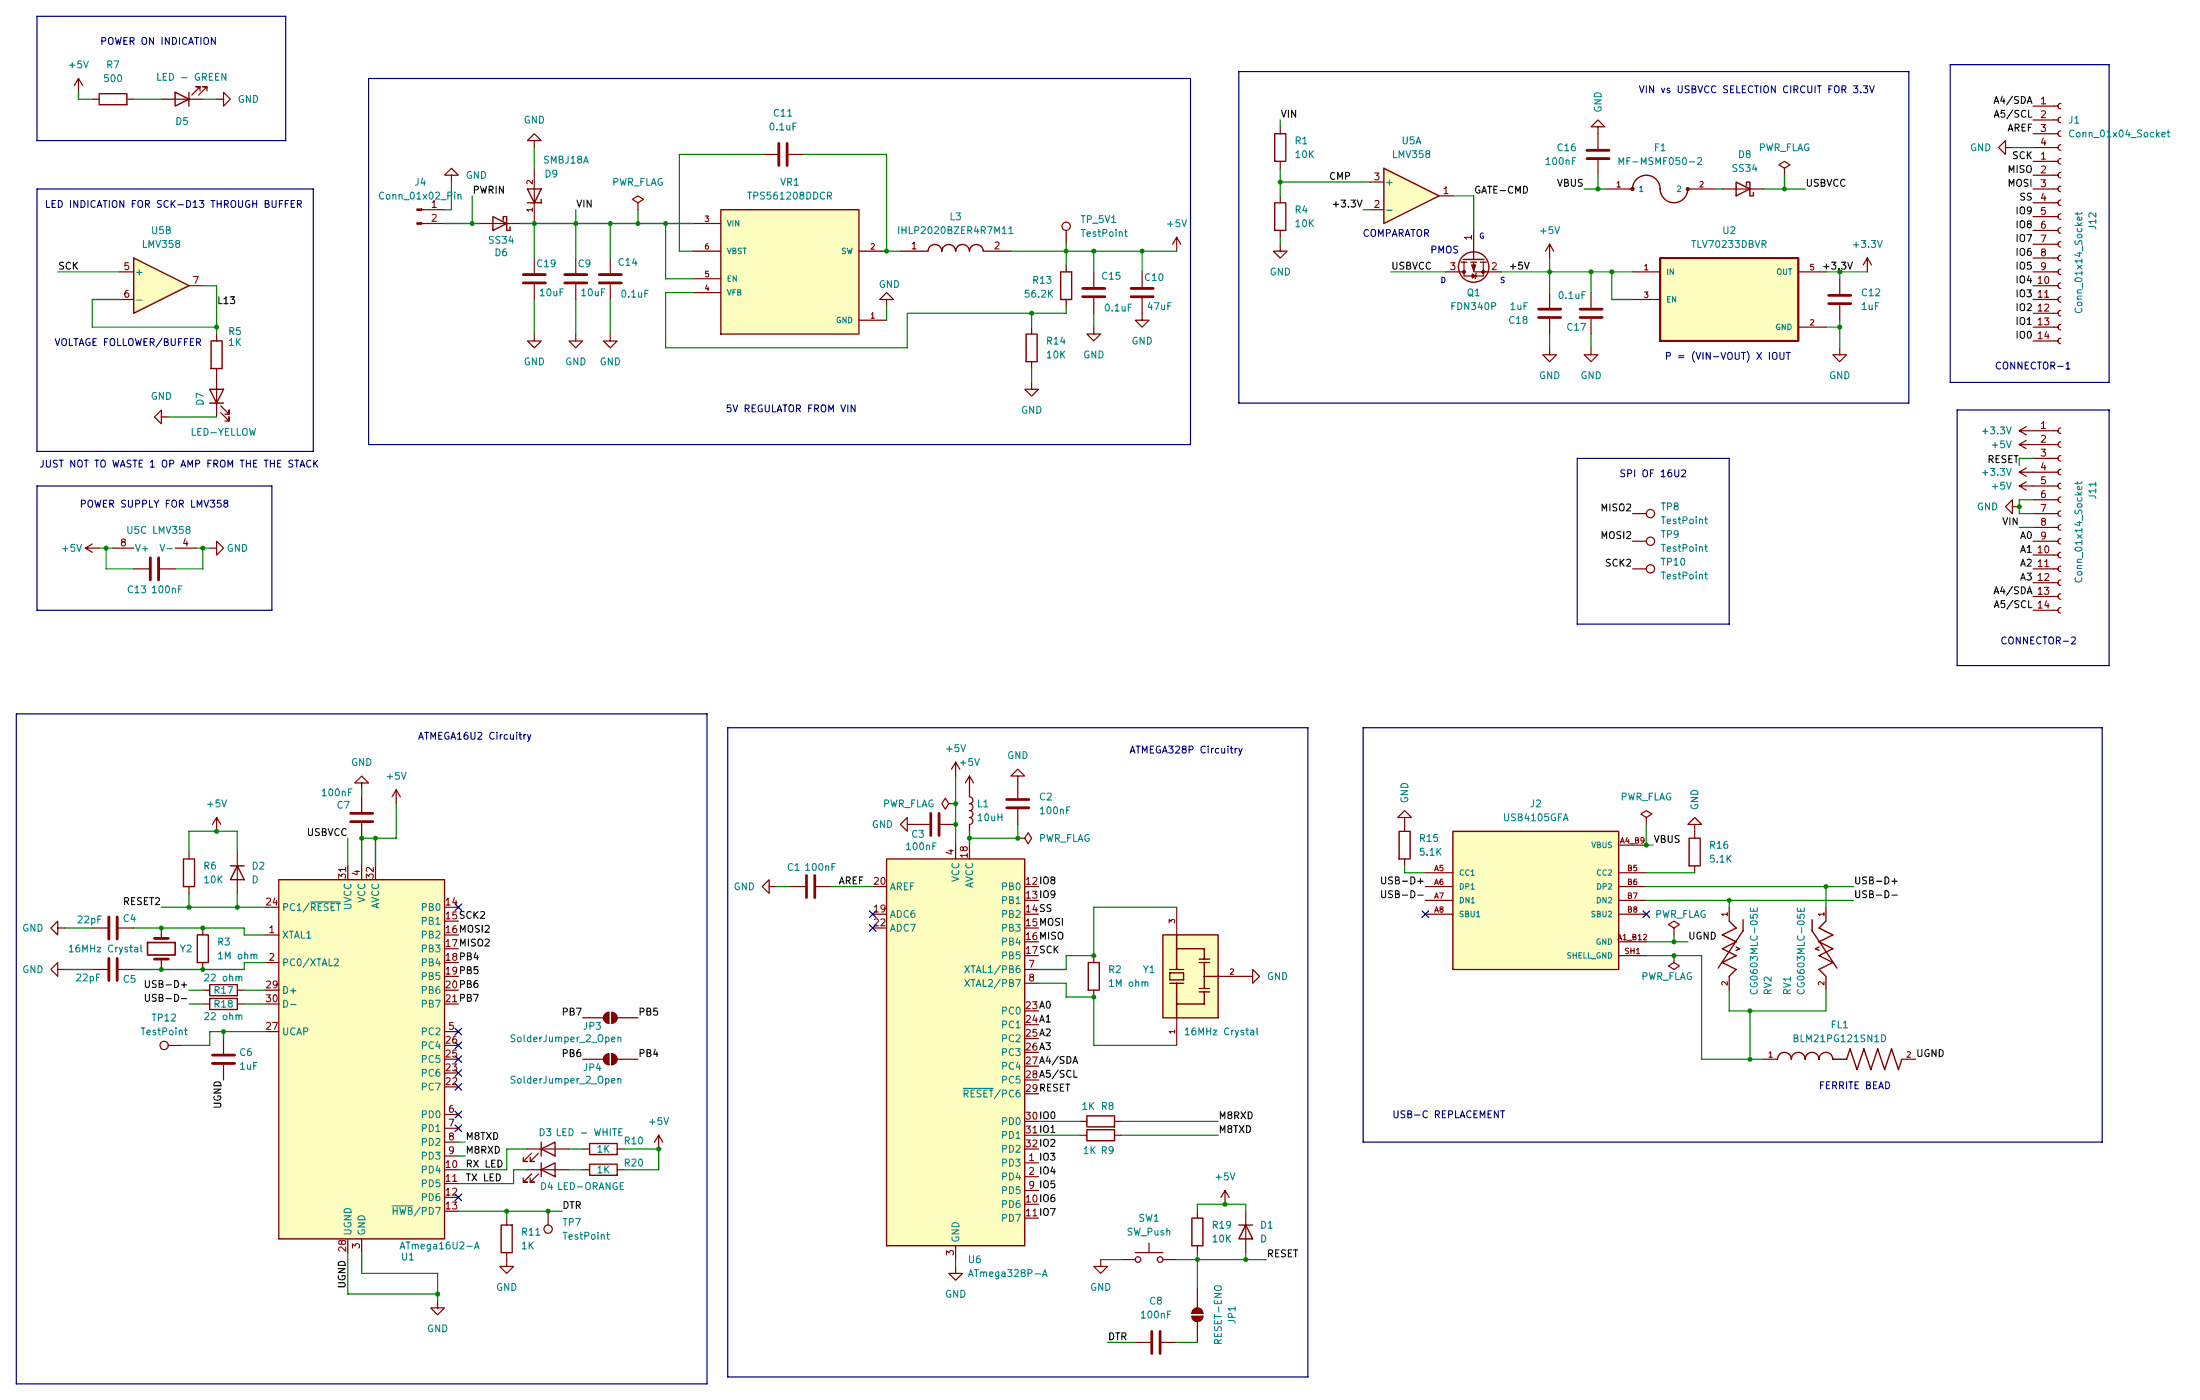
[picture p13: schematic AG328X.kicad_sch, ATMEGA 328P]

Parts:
C1, C2, C3, C7, C8, C13, C16: 100nF; C_0402_1005Metric
C4, C5: 22pF; C_0402_1005Metric
C6: 1uF; C_0402_1005Metric
C9, C19: 10uF; C_0603_1608Metric
C10: 47uF; C_1206_3216Metric
C11, C14, C15, C17: 0.1uF; C_0402_1005Metric
C12, C18: 1uF; C_0603_1608Metric
D1: D; D2 diode
D2: D; D_0603_1608Metric
D3: LED - WHITE; LED_0402_1005Metric
D4: LED-ORANGE; LED_0402_1005Metric
D5: LED - GREEN; LED_0402_1005Metric
D6, D8: SS34; D_SMA
D7: LED-YELLOW; LED_0402_1005Metric
D9: SMBJ18A; D_SMB_Handsoldering; PARTREV 20 - 2
F1: MF-MSMF050-2; FUSM4632X85
FL1: BLM21PG121SN1D; BEADC2012X105N
J1: Conn_01x04_Socket; PinHeader_1x04_P2.00mm_Vertical
J2: USB4105GFA; GCT_USB4105GFA; PARTREV B3
J4: Conn_01x02_Pin; JST_XA_B02B-XASK-1-A_1x02_P2.50mm_Vertical
J11, J12: Conn_01x14_Socket; PinHeader_1x14_P2.00mm_Vertical
JP1: RESET-ENO; SolderJumper-2_P1.3mm_Open_RoundedPad1.0x1.5mm
JP3, JP4: SolderJumper_2_Open; SolderJumper-2_P1.3mm_Open_RoundedPad1.0x1.5mm
L1: 10uH; L_0603_1608Metric
L3: IHLP2020BZER4R7M11; INDPM5552X200N; Manufacturer_Part_Number IHLP2020BZER4R7M11; Mouser Part Number 70-IHLP2020BZER4R7M1
Q1: FDN340P; SOT-23
R1, R4, R6, R14, R19: 10K; R_0402_1005Metric
R2, R3: 1M ohm; R_0402_1005Metric
R5, R8, R9, R10, R11, R20: 1K; R_0402_1005Metric
R7: 500; R_0402_1005Metric
R13: 56.2K; R_0402_1005Metric
R15, R16: 5.1K; R_0402_1005Metric
R17, R18: 22 ohm; R_0402_1005Metric
RV1, RV2: CG0603MLC-05E; VARC1608X56N; PARTREV E
SW1: SW_Push; SW_Tactile_SPST_NO_Straight_CK_PTS636Sx25SMTRLFS
TP7, TP8, TP9, TP10, TP12: TestPoint; TestPoint_Pad_D1.0mm
TP_5V1: TestPoint; TestPoint_Pad_D1.0mm
U1: ATmega16U2-A; TQFP-32_7x7mm_P0.8mm
U2: TLV70233DBVR; SOT95P280X145-5N
U5: LMV358; SO08
U6: ATmega328P-A; TQFP-32_7x7mm_P0.8mm
VR1: TPS561208DDCR; SOT95P280X110-6N; PARTREV April 2017
Y1: 16MHz Crystal; OSC_CSTCE16M0V53-R0; PARTREV 10/24/2022
Y2: 16MHz Crystal; 16MHz Y2

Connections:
+3.3V: C12.1, J11.1, J11.4, U2.5 (OUT), U5.2 (-)
+5V: C3.1, C7.1, C10.1, C13.2, C15.1, C17.2, C18.2, D1.1 (K), D2.1 (K), J11.2, J11.5, L1.1, L3.2, Q1.2 (S), R6.1, R7.1, R10.2, R13.1, R19.1, R20.2, TP_5V1.1 (1_1), U1.4 (VCC), U1.32 (AVCC), U2.1 (IN), U2.3 (EN), U5.8 (V+), U6.4 (VCC), U6.6 (VCC)
/A0: J11.9, U6.23 (PC0)
/A1: J11.10, U6.24 (PC1)
/A2: J11.11, U6.25 (PC2)
/A3: J11.12, U6.26 (PC3)
/A4/SDA: J1.1, J11.13, U6.27 (PC4)
/A5/SCL: J1.2, J11.14, U6.28 (PC5)
/AREF: C1.1, J1.3, U6.20 (AREF)
/CMP: R1.2, R4.1, U5.3 (+)
/DTR: C8.1, R11.2, TP7.1 (1_1), U1.13 (~HWB/PD7)
/GATE-CMD: Q1.1 (G), U5.1
/IO0: J12.14, R8.1, U6.30 (PD0)
/IO1: J12.13, R9.1, U6.31 (PD1)
/IO2: J12.12, U6.32 (PD2)
/IO3: J12.11, U6.1 (PD3)
/IO4: J12.10, U6.2 (PD4)
/IO5: J12.9, U6.9 (PD5)
/IO6: J12.8, U6.10 (PD6)
/IO7: J12.7, U6.11 (PD7)
/IO8: J12.6, U6.12 (PB0)
/IO9: J12.5, U6.13 (PB1)
/L13: R5.1, U5.6 (-), U5.7
/M8RXD: R8.2, U1.9 (PD3)
/M8TXD: R9.2, U1.8 (PD2)
/MISO: J12.2, U6.16 (PB4)
/MISO2: TP8.1 (1_1), U1.17 (PB3)
/MOSI: J12.3, U6.15 (PB3)
/MOSI2: TP9.1 (1_1), U1.16 (PB2)
/PB4: JP4.2 (B), U1.18 (PB4)
/PB5: JP3.2 (B), U1.19 (PB5)
/PB6: JP4.1 (A), U1.20 (PB6)
/PB7: JP3.1 (A), U1.21 (PB7)
/PWRIN: D6.2 (A), J4.2
/RESET: D1.2 (A), J11.3, JP1.2 (B), R19.2, SW1.2, U6.29 (~RESET/PC6)
/RESET2: D2.2 (A), R6.2, U1.24 (PC1/~RESET)
/RX LED: D3.1 (K), U1.10 (PD4)
/SCK: J12.1, U5.5 (+), U6.17 (PB5)
/SCK2: TP10.1 (1_1), U1.15 (PB1)
/SS: J12.4, U6.14 (PB2)
/TX LED: D4.1 (K), U1.11 (PD5)
/USB-D+: J2.A6 (DP1), J2.B6 (DP2), R17.1, RV1.1
/USB-D-: J2.A7 (DN1), J2.B7 (DN2), R18.2, RV2.1
/USBVCC: D8.1 (K), Q1.3 (D), U1.31 (UVCC)
/VIN: C9.1, C14.1, C19.1, D6.1 (K), D9.1, J11.8, R1.1, VR1.3 (VIN), VR1.5 (EN)
GND: C1.2, C2.2, C3.2, C4.1, C5.1, C6.2, C7.2, C9.2, C10.2, C12.2, C13.1, C14.2, C15.2, C16.2, C17.1, C18.1, C19.2, D5.1 (K), D7.1 (K), D9.2, FL1.2, J1.4, J2.A1_B12 (GND), J2.B1_A12 (GND), J4.1, J11.6, J11.7, R4.2, R11.1, R14.2, R15.1, R16.1, SW1.1, U1.3 (GND), U1.28 (UGND), U2.2 (GND), U5.4 (V-), U6.3 (GND), U6.5 (GND), U6.21 (GND), VR1.1 (GND), Y1.2
unnamed: D3.2 (A), R10.1
unnamed: D4.2 (A), R20.1
unnamed: D5.2 (A), R7.2
unnamed: D7.2 (A), R5.2
unnamed: D8.2 (A), F1.2
unnamed: J2.A5 (CC1), R15.2
unnamed: J2.B5 (CC2), R16.2
unnamed: C8.2, JP1.1 (A)
unnamed: R17.2, U1.29 (D+)
unnamed: R18.1, U1.30 (D-)
unnamed: C5.2, R3.2, U1.2 (PC0/XTAL2), Y2.2
unnamed: C6.1, TP12.1 (1_1), U1.27 (UCAP)
unnamed: C4.2, R3.1, U1.1 (XTAL1), Y2.1
unnamed: C2.1, L1.2, U6.18 (AVCC)
unnamed: R2.1, U6.7 (XTAL1/PB6), Y1.3
unnamed: R2.2, U6.8 (XTAL2/PB7), Y1.1
unnamed: C11.1, L3.1, VR1.2 (SW)
unnamed: C11.2, VR1.6 (VBST)
unnamed: R13.2, R14.1, VR1.4 (VFB)
SHELL_GND: FL1.1, J2.SH1 (SHELL_GND), J2.SH2 (SHELL_GND), J2.SH3 (SHELL_GND), J2.SH4 (SHELL_GND), RV1.2, RV2.2
VBUS: C16.1, F1.1, J2.A4_B9 (VBUS), J2.B4_A9 (VBUS)

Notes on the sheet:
LED INDICATION FOR SCK-D13 THROUGH BUFFER
ATMEGA328P Circuitry
POWER ON INDICATION
SPI OF 16U2
5V REGULATOR FROM VIN
P = (VIN-VOUT) X IOUT
VOLTAGE FOLLOWER/BUFFER
COMPARATOR
ATMEGA16U2 Circuitry
JUST NOT TO WASTE 1 OP AMP FROM THE THE STACK
POWER SUPPLY FOR LMV358
PMOS
CONNECTOR-1
USB-C REPLACEMENT
CONNECTOR-2
FERRITE BEAD
VIN vs USBVCC SELECTION CIRCUIT FOR 3.3V

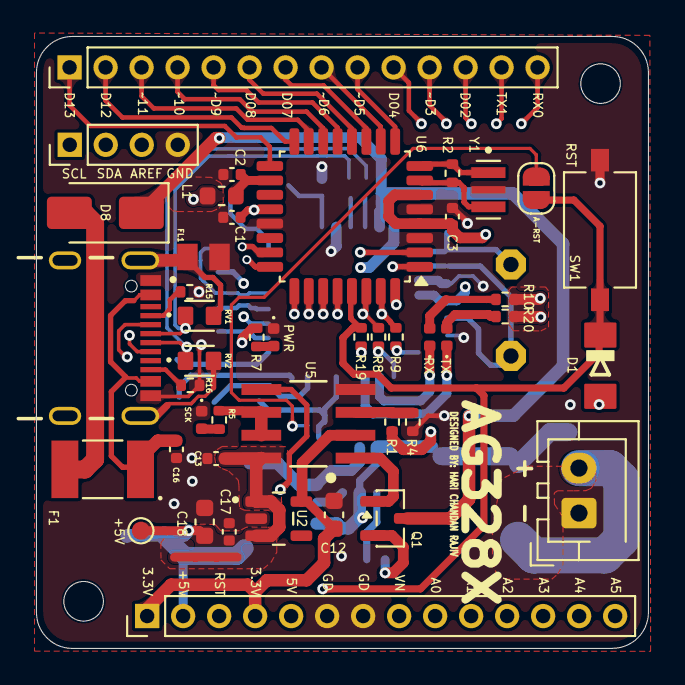
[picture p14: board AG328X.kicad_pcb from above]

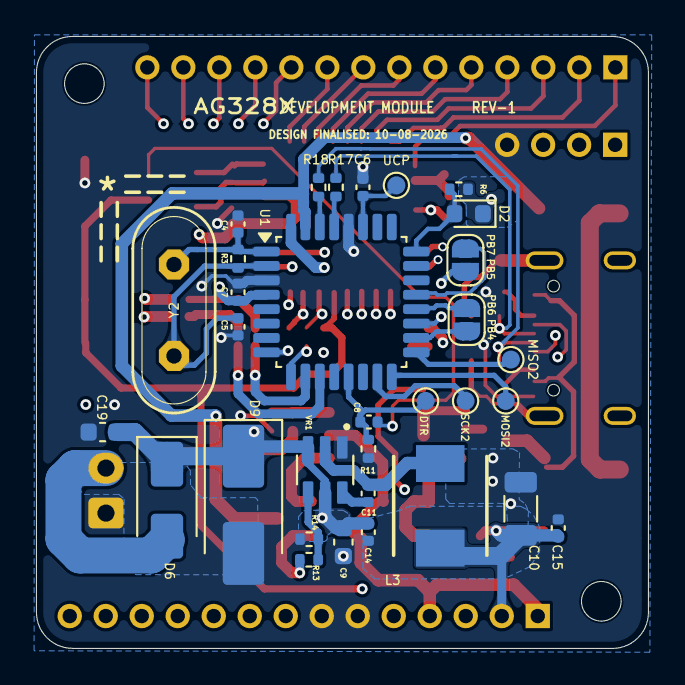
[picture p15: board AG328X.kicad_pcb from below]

Board: 4 copper layers, 34.0 x 34.0 mm, 76 parts (32 on the bottom side), 67 nets.

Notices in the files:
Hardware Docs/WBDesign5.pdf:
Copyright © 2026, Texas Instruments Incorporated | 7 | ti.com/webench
